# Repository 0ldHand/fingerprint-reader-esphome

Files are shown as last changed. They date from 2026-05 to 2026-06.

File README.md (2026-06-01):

# Battery-Powered Fingerprint Reader for Home Assistant

A compact, reliable, and low-power fingerprint reader designed for Home Assistant. Built around the Seed Xiao ESP32-C6 and Grow R503 sensor, with power-saving sensor sleep mode, external antenna for excellent WiFi range, and full Home Assistant integration.

Fingerprint Reader  

---

## ✨ Features

- Full Home Assistant integration (events + services)
- LED feedback (Green = Match, Red = No Match, Purple = Enrolling, etc.)
- Power-saving mode — sensor sleeps after 15 seconds of inactivity
- External 2.4GHz WiFi antenna for strong signal
- Battery powered with 2× 18650 cells (~6400mAh total)
- Solar panel ready
- Clean, modern Home Assistant dashboard included
- OTA updates supported

---

## 📦 Parts List

| Component | Quantity | Link |
|---|---|---|
| Grow R503 Fingerprint Sensor | 1 | [AliExpress](https://www.aliexpress.us/item/2251832867340660.html) |
| Seeed Xiao ESP32-C6 | 1 | [Amazon](https://a.co/d/09wqSHJa) |
| 18650 Battery Cells (3200mAh) | 2 | [18650 Battery Store](https://www.18650batterystore.com/collections/18650-batteries/products/eve-18650-33v) |
| 18650 BMS Protection Board | 1 | [Amazon](https://a.co/d/00WszbO6) |
| 2.4GHz External WiFi Antenna | 1 | [Amazon](https://a.co/d/0hRDYEtv) |
| BC327 PNP Transistor | 1 | [Amazon](https://a.co/d/05GbPzts) |
| 10kΩ Resistor | 1 | [Amazon](https://a.co/d/0dJAFne8) |

---

## 🔧 Wiring

Detailed wiring instructions are included in the [`wiring/wiring_instructions.txt`](wiring/wiring_instructions.txt) file.

**Quick Summary:**
- **Red wire** (VCC) → Switched through PNP transistor (GPIO19)
- **White wire** (3.3VT) → Connected directly to 3.3V
- **Blue wire** (Sensing) → GPIO2
- **Yellow** (TX) → GPIO17
- **Green** (RX) → GPIO16

---

## 🚀 Installation (Using ESPHome Builder in Home Assistant)

This is the easiest way to install the firmware.

### Step 1: Create a New Device in ESPHome

1. Open **Home Assistant** → Go to **ESPHome** (from the sidebar)
2. Click the **+ New Device** button
3. Choose **Create a new device from scratch**
4. Give it a name: `fingerprint-reader`
5. Select your **Seeed Xiao ESP32-C6** board
6. Click **Next** → **Finish**

### Step 2: Paste the Configuration

1. Open the file [`esp-home/fingerprint-reader.yaml`](esp-home/fingerprint-reader.yaml) from this repository
2. Copy **all** the content
3. In ESPHome Builder, click on your new device (`fingerprint-reader`)
4. Delete the default YAML and **paste** the entire content from the file
5. Click **Save**

### Step 3: Update Your Secrets

Make sure you have created the following secrets containing values for your env (Top right in esphome builder)

1. wifi_ssid
2. wifi_password
3. api_encryption_key (create a 32-byte Base64-encoded key for this. e.g. 'openssl rand -base64 32')

### Step 4: Install the Firmware

1. Click the Install button (top right)
2. Choose one of these methods:
3. Plug into this computer (recommended for first install)
4. Install via USB (if your computer has a USB port)
5. Install via network (if the device is already on WiFi)

Wait for the flashing process to complete

### Step 5: Add to Home Assistant
Once the device boots successfully:

It should automatically appear in Settings → Devices & Services → ESPHome
If not, click + Add Integration → Search for ESPHome → Select your device

---

## 🏠 Home Assistant Integration

### Services Available:
- `esphome.fingerprint_reader_enroll`
- `esphome.fingerprint_reader_delete`
- `esphome.fingerprint_reader_delete_all`
- `esphome.fingerprint_reader_cancel_enroll`

### Events:
- `esphome.finger_scan_matched`
- `esphome.finger_scan_unmatched`
- `esphome.enrollment_done`
- `esphome.enrollment_failed`

---

## 📊 Dashboard

A clean and functional Home Assistant dashboard is included in the ['home-assistant/dashboard.yaml'](home-assistant/dashboard.yaml) file.

Features:
- Real-time fingerprint status
- Easy enrollment with ID selector
- Delete single fingerprint or all fingerprints
- WiFi signal strength monitoring

---

## 📸 Screenshots

*(Placeholder for pics)*

- Assembled device
- Dashboard screenshot
- LED feedback examples
- Wiring close-up

---

## To-Do 
1. Impliment essp32c6 deep sleep feature (shouuld drop idle power consuumption down to about 5 micro amps)
2. Add battery voltage monitor service (needs a simple voltage divider)

## 🙏 Credits

- [ESPHome](https://esphome.io/) — The amazing framework that makes this possible
- [Seeed Studio](https://www.seeedstudio.com/) — For the excellent Xiao ESP32-C6
- Grow R503 community for documentation and support

---

**Made with ❤️ for Home Assistant users who want reliable, battery-powered fingerprint control.**

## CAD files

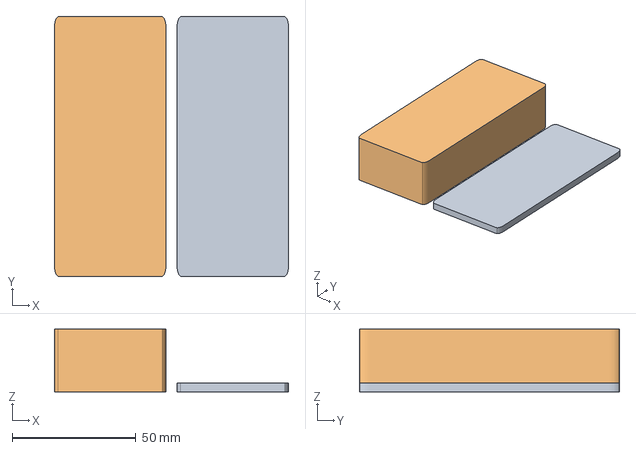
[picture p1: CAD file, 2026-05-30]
3d-models/bambu-studio/esphome-fingerprint-reader.3mf
94.5 x 105.0 x 25.4 mm
Rounded Rectangle_A
Rounded Rectangle_B

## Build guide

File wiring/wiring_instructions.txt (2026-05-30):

================================================================================
           BATTERY-POWERED FINGERPRINT READER - WIRING INSTRUCTIONS
                    Seeed Xiao ESP32-C6 + Grow R503 Sensor
================================================================================

This guide covers the complete wiring for the ESPHome-based fingerprint reader
with power-saving mode, external antenna, and long battery life.

--------------------------------------------------------------------------------
                           1. PINOUT SUMMARY
--------------------------------------------------------------------------------

R503 Fingerprint Sensor (6 wires):
  Red                = VCC (Main Power)     → Through PNP Transistor Collector
  Black              = GND                  → Common Ground
  Yellow             = TX (Data Out)        → GPIO17 (D7 on front)
  Green or Brown     = RX (Data In)         → GPIO16 (D6 on front)
  Blue               = Sensing (Touch)      → GPIO2  (D2 on front)
  White              = 3.3VT (Touch Power)  → Direct to 3V3 (bypass transistor)

PNP Transistor (BC327):
  Emitter   → 3V3 (Xiao)
  Collector → Red wire (R503 VCC)
  Base      → 10kΩ Resistor → GPIO19 (D8 on front)

Power:
  2× 18650 cells + BMS → Xiao battery pads (+ and - on back)

--------------------------------------------------------------------------------
                        2. DETAILED WIRING TABLE
--------------------------------------------------------------------------------

| Component | Wire / Pin | Connect To | Notes |
|---|---|---|---|
| R503 Sensor | Red (VCC) | Transistor Collector | Main power (switched) |
| R503 Sensor | Black (GND) | Common GND | - |
| R503 Sensor | Yellow (TX) | GPIO17 (D7) | UART RX on ESP32 |
| R503 Sensor | Green/Brown (RX) | GPIO16 (D6) | UART TX on ESP32 |
| R503 Sensor | Blue (Sensing) | GPIO2 (D2) | Touch detection |
| R503 Sensor | White (3.3VT) | 3V3 (Xiao) | Must stay powered |
| PNP Transistor | Emitter | 3V3 (Xiao) | Power source |
| PNP Transistor | Collector | Red wire (R503) | Switched power |
| PNP Transistor | Base | 10kΩ Resistor → GPIO19 (D8) | Control pin |
| Battery Pack | + | Xiao BAT+ (back) | From BMS |
| Battery Pack | - | Xiao GND (back) | From BMS |

--------------------------------------------------------------------------------
                    3. STEP-BY-STEP WIRING INSTRUCTIONS
--------------------------------------------------------------------------------

STEP 1: Prepare the Transistor Circuit (Power Control)
----------------------------------------------------
1. Take the BC327 PNP transistor.
2. Solder a 10kΩ resistor to the Base leg.
3. Connect the other end of the 10k resistor to GPIO19 (D8 on front).
4. Connect the Emitter leg to 3V3 on the Xiao.
5. Connect the Collector leg to the Red wire of the R503 sensor.

STEP 2: Connect the R503 Sensor
-------------------------------
1. Connect White wire (3.3VT) directly to 3V3 on the Xiao.
2. Connect Black wire (GND) to any GND pad on the Xiao.
3. Connect Yellow wire (TX) to GPIO17 (D7 on front).
4. Connect Green wire (RX) to GPIO16 (D6 on front).
5. Connect Blue wire (Sensing) to GPIO2 (D2 on front).
6. Connect Red wire (VCC) to the Transistor Collector (from Step 1).

STEP 3: Connect External Antenna
--------------------------------
1. Connect u.FL antenna to the Xiao (if not already done).

STEP 4: Connect Battery Pack
----------------------------
1. Connect the output of the 18650 BMS to the battery pads on the back of the Xiao:
   - BMS + → Xiao BAT+
   - BMS - → Xiao GND (any ground pad)
2. Make sure the BMS is properly connected to the two 18650 cells in parallel.

STEP 5: Double-Check All Connections
------------------------------------
- White wire → Direct 3V3 (never switched)
- Red wire → Only through transistor
- No wires connected to 5V
- All GNDs are common

--------------------------------------------------------------------------------
                      4. TEXT DIAGRAM - TRANSISTOR WIRING
--------------------------------------------------------------------------------

                  3V3 (Xiao)
                     │
                     │
                  Emitter
                     │
              [ BC327 PNP Transistor ]
                     │
                  Collector ──────── Red Wire (R503 VCC)
                     │
Base ───[ 10kΩ ]─────┘
                     │
                  GPIO19 (D8)

White Wire (3.3VT on sensor) ──────→ 3V3 (direct, bypass transistor)

--------------------------------------------------------------------------------
                           5. FINAL CHECKLIST
--------------------------------------------------------------------------------

□ White wire connected directly to 3V3
□ Red wire connected only through transistor Collector
□ Yellow → GPIO17 (D7)
□ Green/Br → GPIO16 (D6)
□ Blue → GPIO2 (D2)
□ Transistor Base → 10k resistor → GPIO19 (D8)
□ Battery connected to back pads via BMS
□ No wires on 5V pin
□ All grounds common

--------------------------------------------------------------------------------
                              NOTES
--------------------------------------------------------------------------------

- The White wire (3.3VT) MUST stay powered at all times for touch detection.
- Only the Red wire (VCC) is switched by the transistor for power saving.
- After wiring, flash the ESPHome config and test the sensor LED turns on when finger is pressed.

================================================================================
                              END OF INSTRUCTIONS
================================================================================

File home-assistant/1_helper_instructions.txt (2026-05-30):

================================================================================
           INSTRUCTION 1: CREATE THE FINGERPRINT ID HELPER
================================================================================

This helper lets you choose which fingerprint ID to enroll or delete.

STEP-BY-STEP:

1. Open Home Assistant
2. Go to **Settings** (bottom left)
3. Click **Devices & Services**
4. Click the **Helpers** tab at the top
5. Click the big **+ Create Helper** button
6. Choose **Number**
7. Fill in the following exactly:

   Name:                    Fingerprint ID
   Icon:                    mdi:fingerprint
   Minimum value:           1
   Maximum value:           127
   Step size:               1
   Mode:                    Box (or Slider - your choice)
   Unit of measurement:     (leave blank)

8. Click **Create**

You should now see a new helper called:
`input_number.fingerprint_id`

This is what you will use in the dashboard to select which fingerprint to enroll or delete.
================================================================================

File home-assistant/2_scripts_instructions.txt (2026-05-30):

================================================================================
           INSTRUCTION 2: CREATE THE SCRIPTS IN HOME ASSISTANT
================================================================================

You need to create **two scripts**:

1. enroll_new_fingerprint
2. delete_fingerprint

────────────────────────────────────────────────────────────────────────────────
SCRIPT 1: enroll_new_fingerprint
────────────────────────────────────────────────────────────────────────────────

1. Go to **Settings → Automations & Scenes → Scripts**
2. Click **+ Create Script**
3. Click the three dots (⋮) in the top right → **Edit in YAML**
4. Delete everything and paste the contents of enroll_new_fingerprint.yaml
5. Click **Save Script**

────────────────────────────────────────────────────────────────────────────────
SCRIPT 2: delete_fingerprint
────────────────────────────────────────────────────────────────────────────────

1. Click **+ Create Script** again
2. Click the three dots (⋮) → **Edit in YAML**
4. Delete everything and paste the contents of delete_fingerprint.yaml
5. Click **Save Script**
You now have two scripts ready to use from the dashboard.
================================================================================

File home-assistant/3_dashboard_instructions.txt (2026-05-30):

================================================================================
           INSTRUCTION 3: ADD THE DASHBOARD
================================================================================

1. In Edit Dashboard mode, click the three dots (⋮) → **Raw configuration editor**
2. Delete everything and paste the full YAML from the file:
   `home-assistant/dashboard.yaml`

3. Click **Save**

This is the cleanest and fastest method if you want the exact layout.
================================================================================

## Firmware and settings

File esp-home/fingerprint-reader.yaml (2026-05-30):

esphome:
  name: fingerprint-reader
  friendly_name: Fingerprint Reader
  # ================== EXTERNAL ANTENNA ==================
  on_boot:
    priority: 650
    then:
      - output.turn_off: rf_switch_enable
      - delay: 150ms
      - output.turn_on: rf_antenna_select
      - wifi.disable:
      - delay: 100ms
      - wifi.enable:

# ================== EXTERNAL ANTENNA (Outputs) ==================
output:
  - platform: gpio
    pin: GPIO3
    id: rf_switch_enable

  - platform: gpio
    pin: GPIO14
    id: rf_antenna_select

esp32:
  board: seeed_xiao_esp32c6
  variant: esp32c6
  flash_size: 4MB
  framework:
    type: esp-idf



uart:
  id: fingerprint_uart
  rx_pin: GPIO17
  tx_pin: GPIO16
  baud_rate: 57600

fingerprint_grow:
  # Sensing pin (blue wire) - must stay enabled
  sensing_pin:
    number: GPIO2
    

  # Power control - Only switching the Red wire (VCC)
  sensor_power_pin:
    number: GPIO19          # D8 - Good GPIO
    inverted: true

  idle_period_to_sleep: 15s   # Sensor sleeps after 15 seconds of inactivity

  # ================== LED & EVENT FEEDBACK ==================
  on_finger_scan_matched:
    - fingerprint_grow.aura_led_control:
        state: FLASHING
        color: GREEN
        speed: 50
        count: 4
    - homeassistant.event:
        event: esphome.finger_scan_matched
        data:
          finger_id: !lambda 'return finger_id;'
          confidence: !lambda 'return confidence;'

  on_finger_scan_unmatched:
    - fingerprint_grow.aura_led_control:
        state: FLASHING
        color: RED
        speed: 100
        count: 6
    - homeassistant.event:
        event: esphome.finger_scan_unmatched

  on_finger_scan_misplaced:
    - homeassistant.event:
        event: esphome.frontdoor_finger_scan_misplaced

  on_finger_scan_invalid:
    - homeassistant.event:
        event: esphome.finger_scan_invalid



  on_enrollment_scan:
    - fingerprint_grow.aura_led_control:
        state: FLASHING
        color: BLUE
        speed: 125
        count: 2    
    - homeassistant.event:
        event: esphome.enrollment_scan
        data:
          finger_id: !lambda 'return finger_id;'
          scan_num: !lambda 'return scan_num;'

  on_enrollment_done:
    - fingerprint_grow.aura_led_control:
        state: FLASHING
        color: BLUE
        speed: 75
        count: 4
    - homeassistant.event:
        event: esphome.enrollment_done
        data:
          finger_id: !lambda 'return finger_id;'

  on_enrollment_failed:
    - homeassistant.event:
        event: esphome.enrollment_failed
        data:
          finger_id: !lambda 'return finger_id;'

sensor:
  - platform: fingerprint_grow
    fingerprint_count:
      name: "Stored Fingerprints"
    last_finger_id:
      name: "Last Scanned Finger ID"
    last_confidence:
      name: "Last Scan Confidence"
  - platform: wifi_signal
    name: "WiFi Signal"
    update_interval: 60s
    icon: mdi:wifi


wifi:
  ssid: !secret wifi_ssid
  password: !secret wifi_password
  output_power: 19.5dB

api:
  encryption:
    key: !secret api_encryption_key

  actions:
    - action: enroll
      variables:
        finger_id: int
        num_scans: int
      then:
        - fingerprint_grow.aura_led_control:
            state: ALWAYS_ON
            color: PURPLE
            speed: 0
            count: 0
        - delay: 400ms
        - fingerprint_grow.enroll:
            finger_id: !lambda 'return finger_id;'
            num_scans: !lambda 'return num_scans;'

    - action: cancel_enroll
      then:
        - fingerprint_grow.cancel_enroll:

    - action: delete
      variables:
        finger_id: int
      then:
        - fingerprint_grow.delete:
            finger_id: !lambda 'return finger_id;'

    - action: delete_all
      then:
        - fingerprint_grow.delete_all:

ota:
  - platform: esphome

logger:
  baud_rate: 0
